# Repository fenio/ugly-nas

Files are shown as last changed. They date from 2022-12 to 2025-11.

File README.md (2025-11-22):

name

## DIY 8-disks NAS based on Odroid H3+ under $800 with disks

### Why is it ugly?

Well to be honest it's not so ugly anymore. 

But early case versions were really [ugly](/ugly) and when I eventually created decently looking case I decided to leave its name.

### So how does it look now?

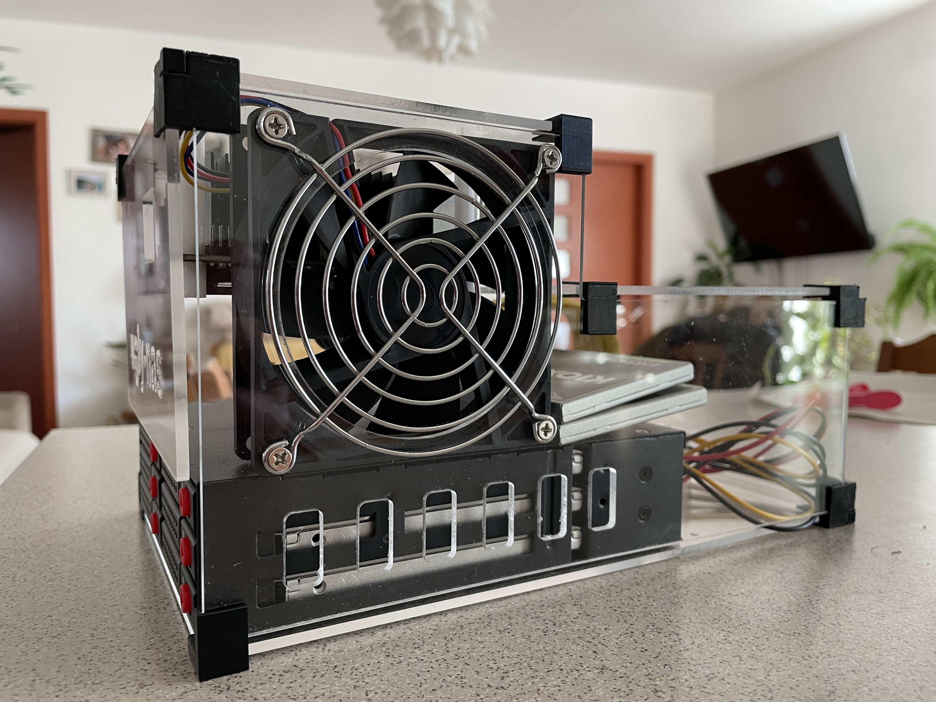
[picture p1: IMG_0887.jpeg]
nas1

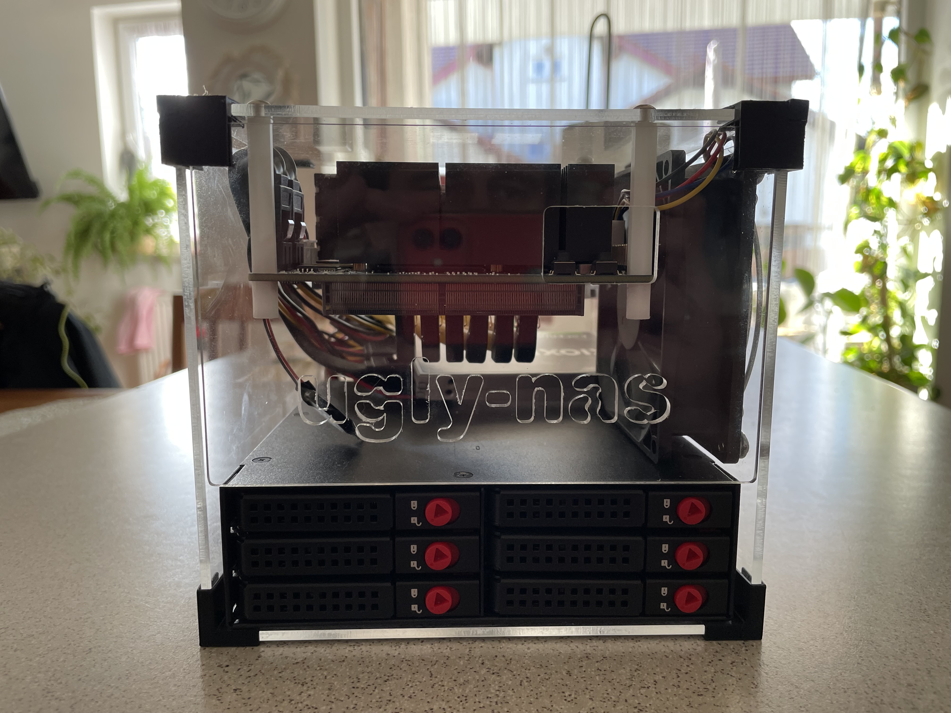
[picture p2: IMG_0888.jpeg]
nas2

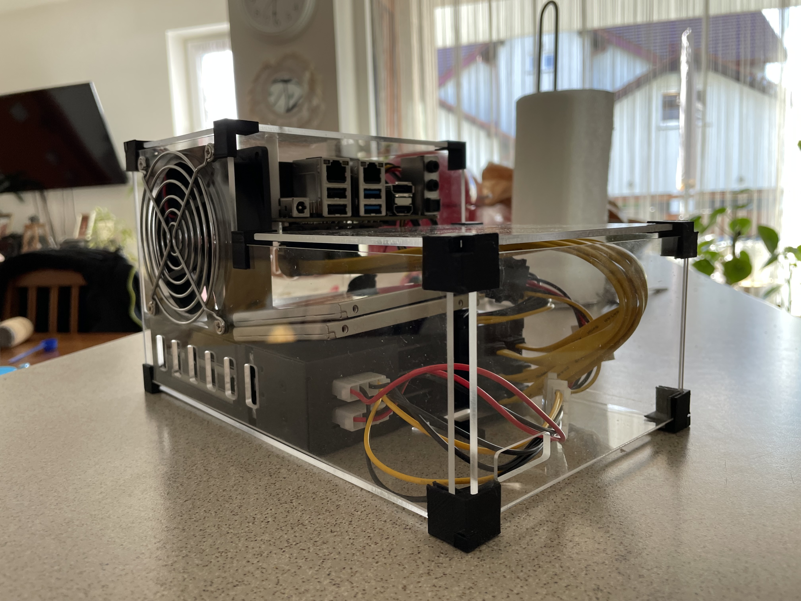
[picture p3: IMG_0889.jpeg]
nas3

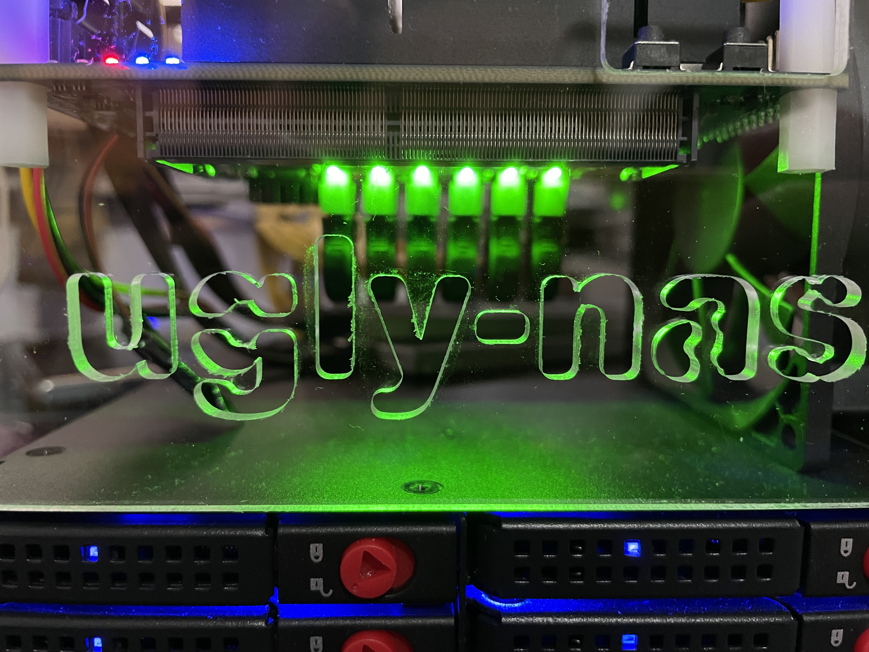
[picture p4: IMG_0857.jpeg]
nas4


Except it no longer has additional PSU for enclosure. Everything is powered using Odroid PSU.

### Cost (June 2023):

| Part  | USD  |
|---|---:|
| [Odroid H3+](https://www.hardkernel.com/shop/odroid-h3-plus/) | 165.00 |
| [64GB eMMC Module](https://www.hardkernel.com/shop/64gb-emmc-module-h2/) | 29.00 |
| [Samsung 32GB DDR4](https://www.hardkernel.com/shop/samsung-32gb-ddr4-pc4-25600-so-dimm/) | 99.00 |
| [Power Supply Unit](https://www.hardkernel.com/shop/15v-4a-power-supply-asia-korea-plug-copy/) | 9.40 |
| 2 x [SATA/Power cables for disks](https://www.hardkernel.com/shop/sata-data-and-power-cable/) | 6.00 |
| [Case Type 5](https://www.hardkernel.com/shop/odroid-h3-case-type-5/) | 20.00 |
| Shipping from hardkernel.com to Poland | 39.43 |
| 8 x [Kioxia 2.5" SSD 480GB drives](https://www.ebay.com/itm/134327464843) | ~330.00 |
| [6-bays enclosure](https://aliexpress.com/item/32921898033.html) | 48.29 |
| [PCI-E SATA extender for 6 ports](https://aliexpress.com/item/1005004374186238.html) | 24.80 |
| 6 x [Profiled SATA cables](https://pl.aliexpress.com/item/1005002384391035.html) | 16.74 |
| [MOLEX splitter](https://aliexpress.com/item/1005004236892928.html) | 1.71 |
| [SATA splitter](https://pl.aliexpress.com/item/10000330531380.html) | 1.57 |
| [Power extension](https://pl.aliexpress.com/item/1005001338498358.html) | 0.84 |
| **Sum** | **791.78** | 

Beware that I spent much more on experimenting with different setups. The final cost above is after refining the best solution.

If you opt for a self-designed [case](/case), purchasing a fan and supports separately is necessary.
From the [listing](https://www.hardkernel.com/shop/odroid-h3-case-type-5/) you will need these parts:

* G. 1 x 92x92x25mm DC 5V Cooling Fan
* H. 1 x 92mm Stainless Cooling Fan Grill
* I. 2 x 10mm (M/F) PCB Supports
* J. 1 x 40mm (M/F) PCB Supports
* K. 2 x 40mm (F/F) PCB Supports
* L. 4 x M5 PC Fan Screws
* N. 4 x 6mm M3 Truss Head Bolts

Assembling these parts individually may save some money, but purchasing the case directly from Odroid is more convenient for acquiring all necessary components in one go.

### Performance

    root@nas[/mnt/storage]# /root/fio --randrepeat=1 --ioengine=libaio --direct=1 --gtod_reduce=1 --name=test --filename=test.fio --bs=4k --iodepth=64 --size=1G --readwrite=randrw --rwmixread=80
    test: (g=0): rw=randrw, bs=(R) 4096B-4096B, (W) 4096B-4096B, (T) 4096B-4096B, ioengine=libaio, iodepth=64
    fio-3.25
    Starting 1 process
    test: Laying out IO file (1 file / 1024MiB)
    Jobs: 1 (f=1): [m(1)][100.0%][r=134MiB/s,w=33.0MiB/s][r=34.3k,w=8701 IOPS][eta 00m:00s]
    test: (groupid=0, jobs=1): err= 0: pid=691249: Mon Dec  5 18:10:27 2022
      read: IOPS=22.9k, BW=89.6MiB/s (93.9MB/s)(819MiB/9142msec)
       bw (  KiB/s): min=21781, max=165208, per=99.06%, avg=90861.61, stdev=42994.49, samples=18
       iops        : min= 5445, max=41302, avg=22715.33, stdev=10748.69, samples=18
      write: IOPS=5744, BW=22.4MiB/s (23.5MB/s)(205MiB/9142msec); 0 zone resets
       bw (  KiB/s): min= 5343, max=41728, per=99.04%, avg=22756.61, stdev=10894.22, samples=18
       iops        : min= 1335, max=10432, avg=5689.06, stdev=2723.60, samples=18
      cpu          : usr=5.09%, sys=78.22%, ctx=5155, majf=4, minf=7
      IO depths    : 1=0.1%, 2=0.1%, 4=0.1%, 8=0.1%, 16=0.1%, 32=0.1%, >=64=100.0%
         submit    : 0=0.0%, 4=100.0%, 8=0.0%, 16=0.0%, 32=0.0%, 64=0.0%, >=64=0.0%
         complete  : 0=0.0%, 4=100.0%, 8=0.0%, 16=0.0%, 32=0.0%, 64=0.1%, >=64=0.0%
         issued rwts: total=209630,52514,0,0 short=0,0,0,0 dropped=0,0,0,0
         latency   : target=0, window=0, percentile=100.00%, depth=64

    Run status group 0 (all jobs):
       READ: bw=89.6MiB/s (93.9MB/s), 89.6MiB/s-89.6MiB/s (93.9MB/s-93.9MB/s), io=819MiB (859MB), run=9142-9142msec
      WRITE: bw=22.4MiB/s (23.5MB/s), 22.4MiB/s-22.4MiB/s (23.5MB/s-23.5MB/s), io=205MiB (215MB), run=9142-9142msec

And same test with 10M file instead of 1G:

    root@nas[/mnt/storage]# /root/fio --randrepeat=1 --ioengine=libaio --direct=1 --gtod_reduce=1 --name=test --filename=test.fio --bs=4k --iodepth=64 --size=10M --readwrite=randrw --rwmixread=80
    test: (g=0): rw=randrw, bs=(R) 4096B-4096B, (W) 4096B-4096B, (T) 4096B-4096B, ioengine=libaio, iodepth=64
    fio-3.25
    Starting 1 process

    test: (groupid=0, jobs=1): err= 0: pid=695373: Mon Dec  5 18:25:17 2022
      read: IOPS=97.1k, BW=379MiB/s (398MB/s)(8156KiB/21msec)
      write: IOPS=24.8k, BW=96.9MiB/s (102MB/s)(2084KiB/21msec); 0 zone resets
      cpu          : usr=0.00%, sys=90.00%, ctx=0, majf=0, minf=7
      IO depths    : 1=0.1%, 2=0.1%, 4=0.2%, 8=0.3%, 16=0.6%, 32=1.2%, >=64=97.5%
         submit    : 0=0.0%, 4=100.0%, 8=0.0%, 16=0.0%, 32=0.0%, 64=0.0%, >=64=0.0%
         complete  : 0=0.0%, 4=100.0%, 8=0.0%, 16=0.0%, 32=0.0%, 64=0.1%, >=64=0.0%
         issued rwts: total=2039,521,0,0 short=0,0,0,0 dropped=0,0,0,0
         latency   : target=0, window=0, percentile=100.00%, depth=64

    Run status group 0 (all jobs):
       READ: bw=379MiB/s (398MB/s), 379MiB/s-379MiB/s (398MB/s-398MB/s), io=8156KiB (8352kB), run=21-21msec
      WRITE: bw=96.9MiB/s (102MB/s), 96.9MiB/s-96.9MiB/s (102MB/s-102MB/s), io=2084KiB (2134kB), run=21-21msec

With iozone:

    root@nas[/mnt/storage]# /root/iozone -e -I -a -s 1G -r 4k -r 16k -r 512k -r 1024k -r 16384k -i 0 -i 1 -i 2     
            Iozone: Performance Test of File I/O
                    Version $Revision: 3.489 $
                    Compiled for 64 bit mode.
                    Build: linux-AMD64 
    
            Contributors:William Norcott, Don Capps, Isom Crawford, Kirby Collins
                         Al Slater, Scott Rhine, Mike Wisner, Ken Goss
                         Steve Landherr, Brad Smith, Mark Kelly, Dr. Alain CYR,
                         Randy Dunlap, Mark Montague, Dan Million, Gavin Brebner,
                         Jean-Marc Zucconi, Jeff Blomberg, Benny Halevy, Dave Boone,
                         Erik Habbinga, Kris Strecker, Walter Wong, Joshua Root,
                         Fabrice Bacchella, Zhenghua Xue, Qin Li, Darren Sawyer,
                         Vangel Bojaxhi, Ben England, Vikentsi Lapa,
                         Alexey Skidanov, Sudhir Kumar.
    
            Run began: Mon Jan 16 16:52:27 2023
    
            Include fsync in write timing
            O_DIRECT feature enabled
            Auto Mode
            File size set to 1048576 kB
            Record Size 4 kB
            Record Size 16 kB
            Record Size 512 kB
            Record Size 1024 kB
            Record Size 16384 kB
            Command line used: /root/iozone -e -I -a -s 1G -r 4k -r 16k -r 512k -r 1024k -r 16384k -i 0 -i 1 -i 2
            Output is in kBytes/sec
            Time Resolution = 0.000001 seconds.
            Processor cache size set to 1024 kBytes.
            Processor cache line size set to 32 bytes.
            File stride size set to 17 * record size.
                                                                  random    random     bkwd    record    stride                                    
                  kB  reclen    write  rewrite    read    reread    read     write     read   rewrite      read   fwrite frewrite    fread  freread
             1048576       4   310964   292306  1178512  1179537   173968   195313                                                                
             1048576      16   293274   307902  2134753  2159181   626843   278066                                                                
             1048576     512  1010432  1793142  6357664  2866019  3240346   999201                                                                
             1048576    1024   798928  1539648  4325665  4094047  6342773  1731892                                                                
             1048576   16384   809463  1588195  4512099  2468875  2813374  1110396                                                                
    
    iozone test complete.

And simple dd:

    root@nas[~]# dd if=/dev/zero of=/mnt/storage/file bs=1M count=10K
    10240+0 records in
    10240+0 records out
    10737418240 bytes (11 GB, 10 GiB) copied, 6.14285 s, 1.7 GB/s
    root@nas[~]# dd if=/mnt/storage/file of=/dev/null bs=1M count=10K
    10240+0 records in
    10240+0 records out
    10737418240 bytes (11 GB, 10 GiB) copied, 2.27149 s, 4.7 GB/s

Feel free to ping me if you want me to run any other tests.

### Power consumption in Watts

| State | Peak | Avg |
|---|---:|---:|
| standby | - | 3.6 |
| boot | 24.2 | ~17 |
| idling | 17.7 | ~14 |
| 1 VM running | 22.3 | ~16 |
| VM + stress CPU + fio test | 30.8 | ~28 |

Note: Don't try to use HDD instead of SDD with my power supply setup... it won't work almost for sure.

### Does it support ECC?

No. It can't.

### What software does it run?

It runs TrueNAS Scale.
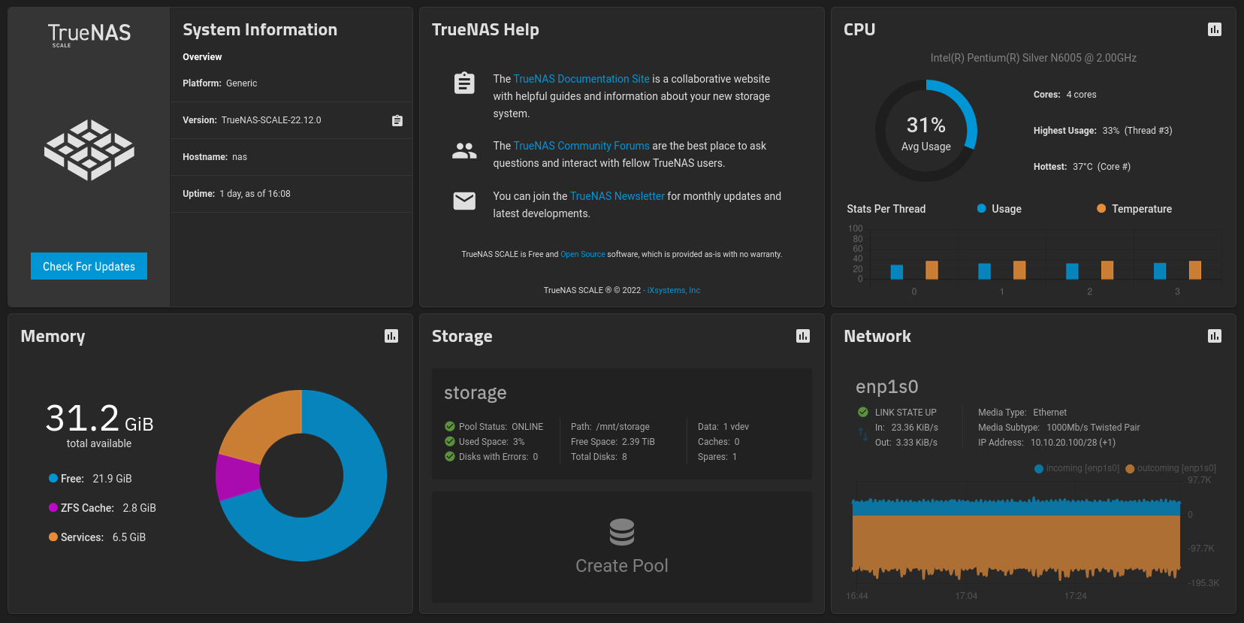
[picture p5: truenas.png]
truenas


Side note. Make sure to use the latest intel microcode or you'll end up with VM's freezing here and there pretty often.
You have to have microcode version "24" to have stable virtualization.

    root@nas[~]# grep -m1 microcode /proc/cpuinfo 
    microcode       : 0x24000024

If it shows 0x24000023 then you definitely want to update it.

### Can it be any cheaper?

Yup.

Without disks it's below $500 ;)

Also it should still work pretty decent if you switch:
  * H3+ -> H3 - 36$ less
  * eMMC 64GB -> 32GB - $10 less
  * RAM 32GB -> 16GB - $54 less

So without disks it can be built for about $375.

### Why are two disks directly plugged into Odroid not part of enclosure?

Odroid [doesn't](https://wiki.odroid.com/odroid-h3/hardware) support hotplug for devices directly attached to it so it doesn't really make sense to make them part of enclosure.

### How to get that lovely case?

All needed parts are listed [there](/case).

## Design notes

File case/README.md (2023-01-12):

# Parts needed to create the case

## Plexiglass to be carved by local CNC supplier (3mm)

* [Front](front.svg)
* [Back](back.svg)
* [Left](left.svg)
* [Right](right.svg)
* [Shelve](shelve.svg)
* [Top](top.svg)
* [Bottom](bottom.svg)

## Connectors to be printed in 3D

| Part | Pcs | Link | File |
|---|----:|---|---|
| 3-way connector | 6 | https://www.tinkercad.com/things/dNCOjgzWop4-corner-connector-3-way | [Corner connector 3-way](Corner-3W.stl) |
| 2-way open | 4 | https://www.tinkercad.com/things/0fqsxl175nB-corner-connector-2-way-half-open | [Corner connector 2-way open](Corner-2W-open.stl) |
| 2-way | 4 | https://www.tinkercad.com/things/dEiUtZarAht-corner-connector-2-way | [Corner connector 2-way](Corner-2W.stl) |
| Peg | 6 | https://www.tinkercad.com/things/g6Oe3tnbkLx-peg | [Peg](Peg.stl) |
| Blocker | 1 | https://www.tinkercad.com/things/gxXk9fNjbbF-blocker | [Blocker](Blocker.stl) |

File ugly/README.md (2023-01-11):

Case evolution

# Why was it ugly?

# Odroid case
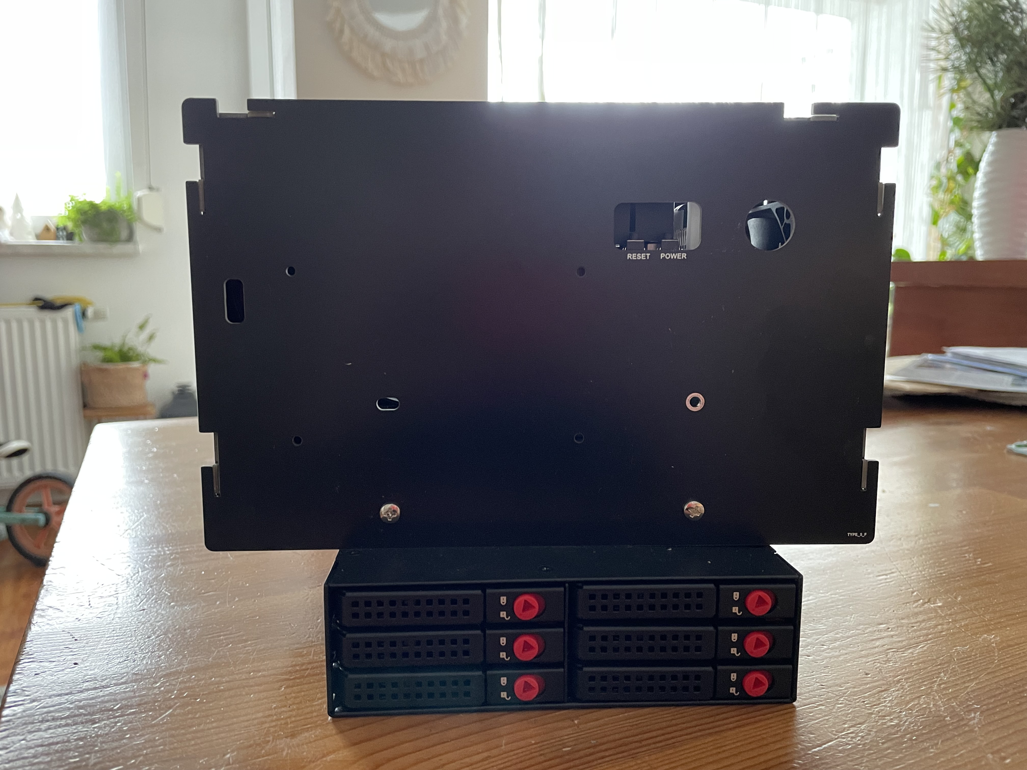
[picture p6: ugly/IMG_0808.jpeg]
early1

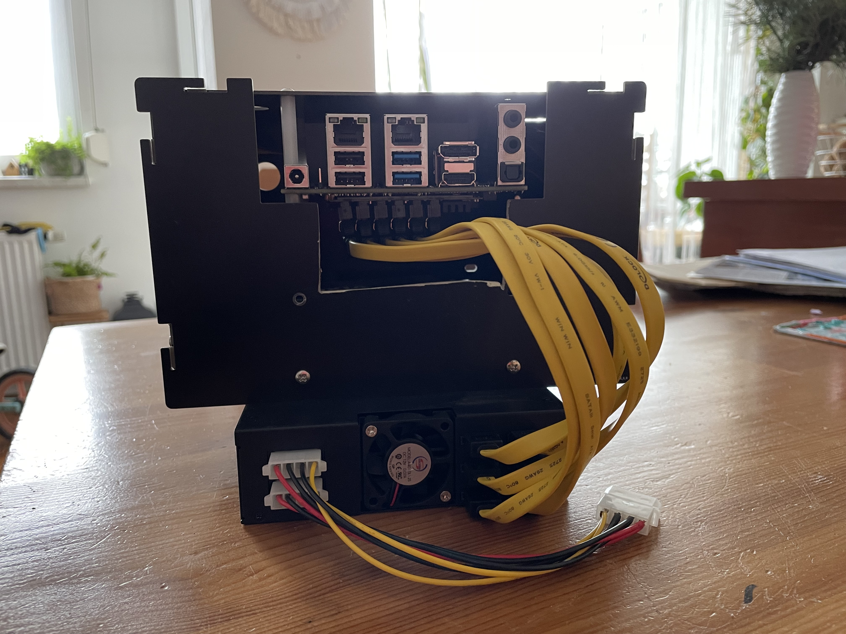
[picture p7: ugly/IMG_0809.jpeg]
early2

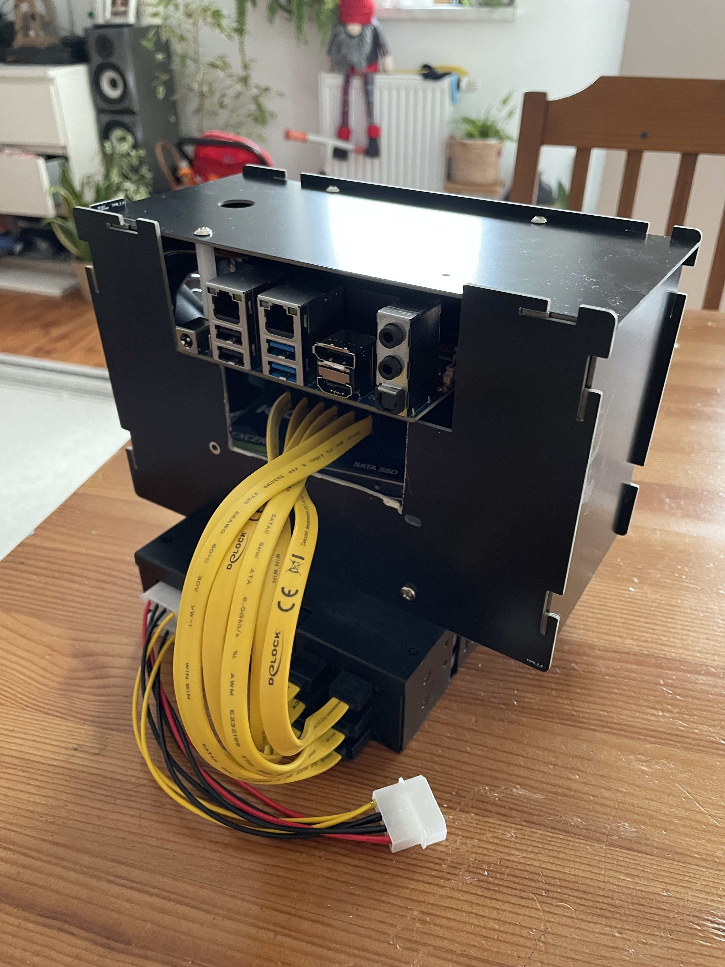
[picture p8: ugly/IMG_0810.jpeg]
early3


# Early attempt
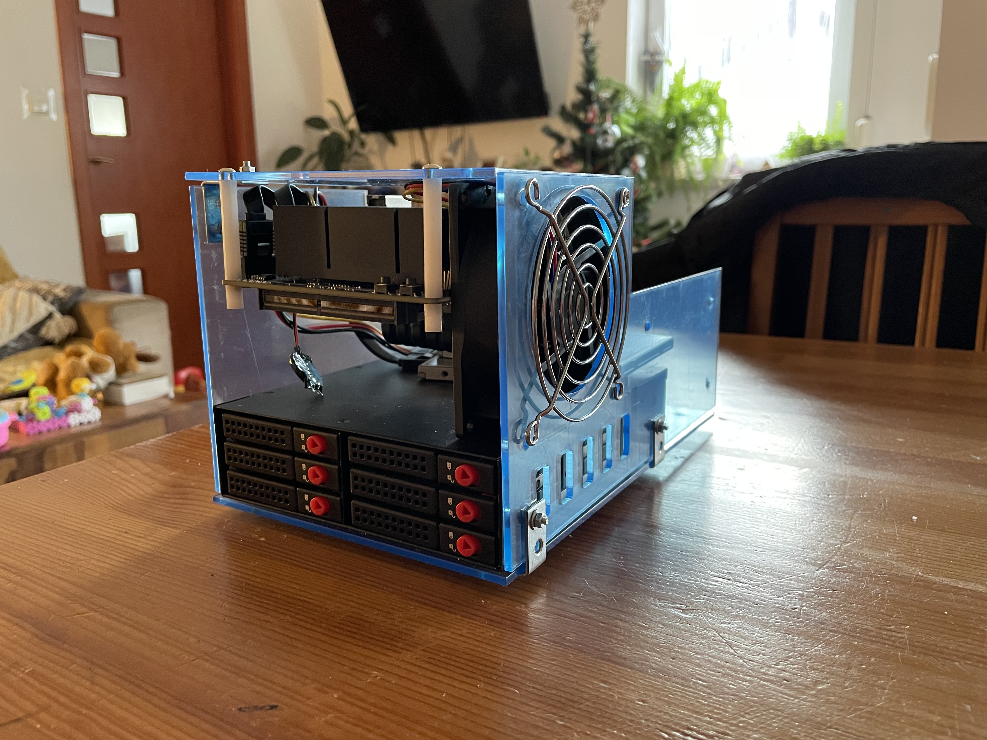
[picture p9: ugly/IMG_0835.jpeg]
alpha1

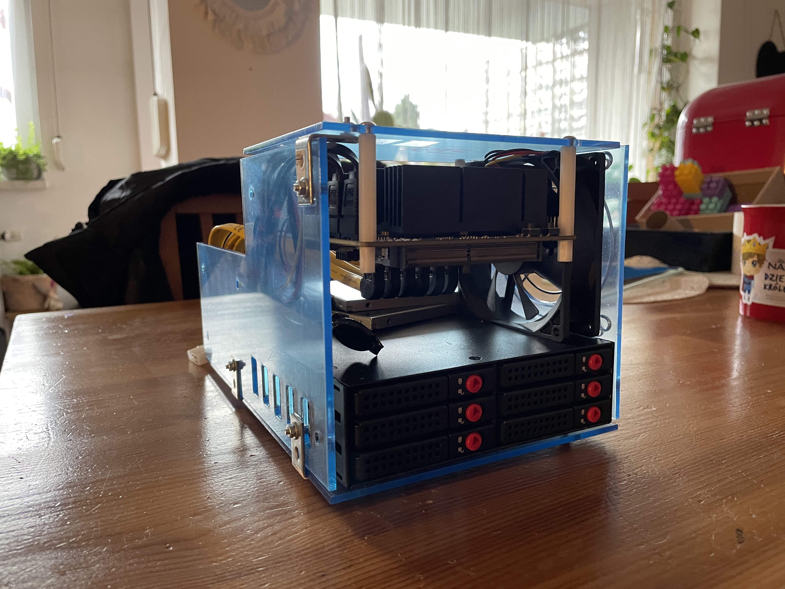
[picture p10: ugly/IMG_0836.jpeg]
alpha2

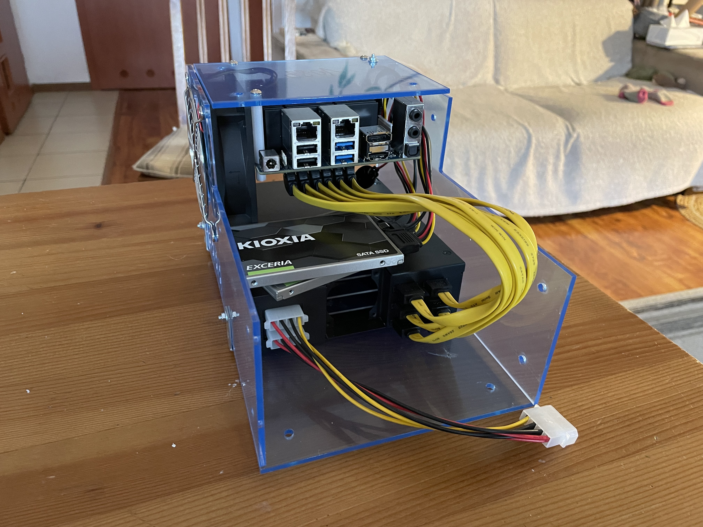
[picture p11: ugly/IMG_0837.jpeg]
alpha3


# Another approach
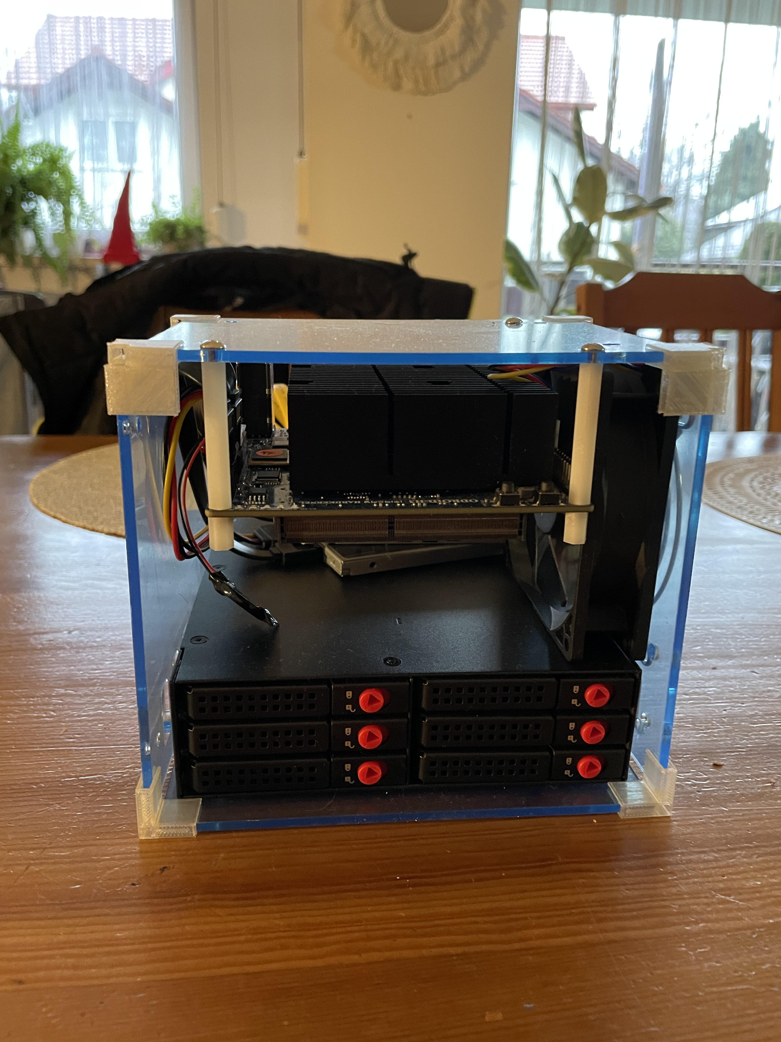
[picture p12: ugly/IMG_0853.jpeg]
beta1


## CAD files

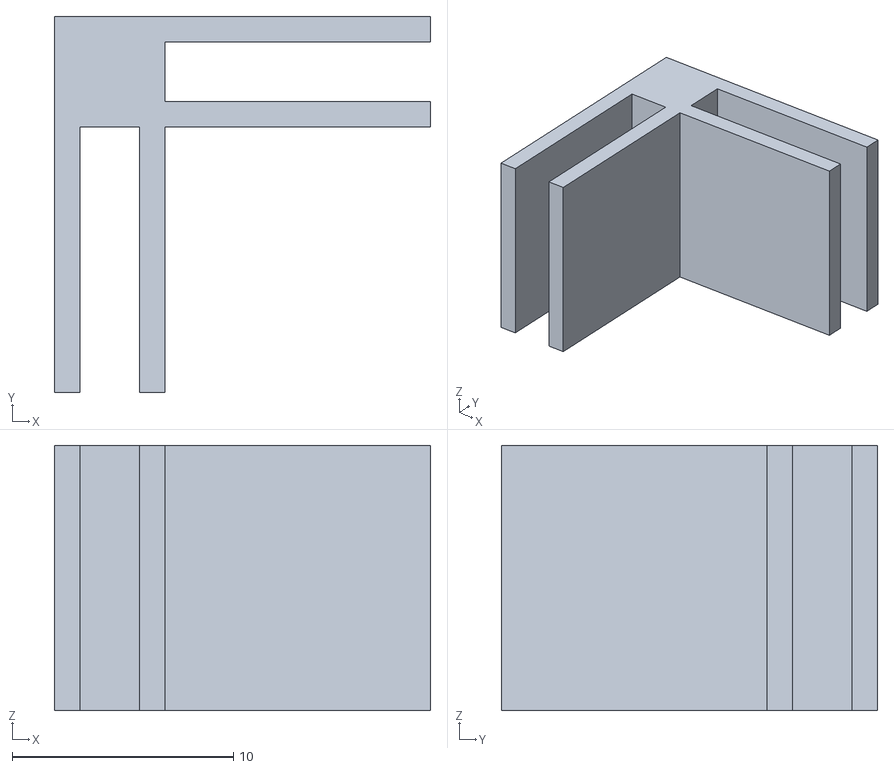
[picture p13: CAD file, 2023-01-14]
case/Corner-2W-open.stl
17.0 x 17.0 x 12.0

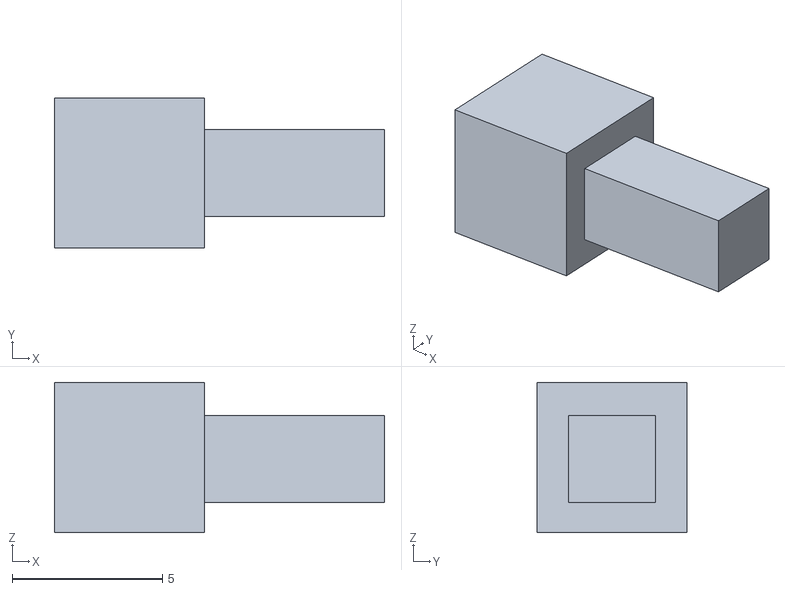
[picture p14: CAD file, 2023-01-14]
case/Peg.stl
11.0 x 5.00 x 5.00

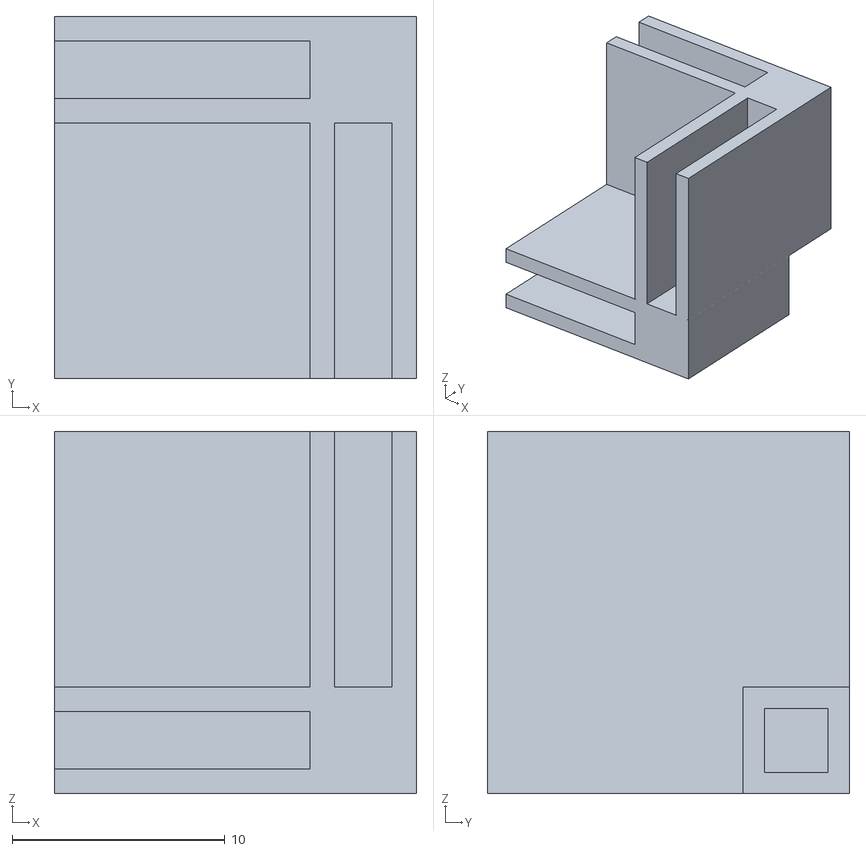
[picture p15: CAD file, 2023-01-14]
case/Corner-3W.stl
17.0 x 17.0 x 17.0

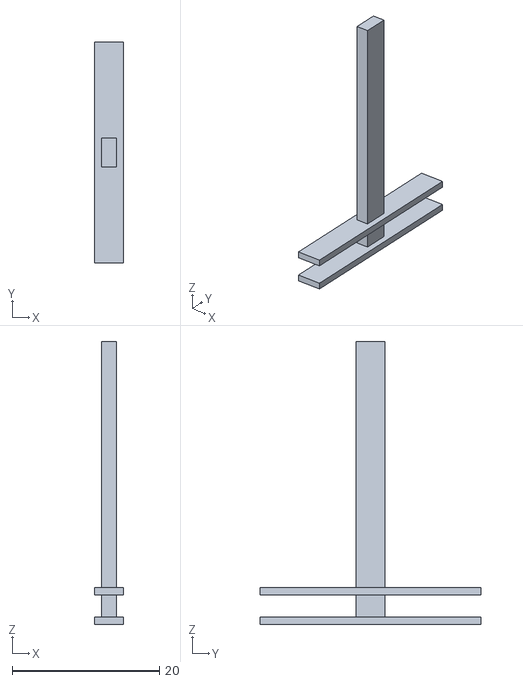
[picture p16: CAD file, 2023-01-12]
case/Blocker.stl
4.00 x 30.0 x 38.5

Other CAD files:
case/Corner-2W.stl

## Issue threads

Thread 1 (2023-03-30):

Need help with providing power to disk enclosure in UGLY NAS

lambscaped, 2023-03-30:
I've been working on building my own NAS using your project as a guide and I really like it! However, I'm having trouble figuring out how to provide power to the disk enclosure through the odroid H3+. I was hoping you could help me by letting me know what physical components you used and how you made it work.

Thank you for your contribution to the community, and I look forward to hearing back from you!

Best regards,
Sergio Leyva

fenio, 2023-03-31:
Hey @lambscaped

Thanks for your report and yeah I should probably spend some time to update description to include final list of components.
Basically you just need two relatively cheap splitters in addition to what's listed.

I bought them on Allegro (let's call it Polish equivalent of Ebay).
[https://allegro.pl/oferta/kabel-zasilajacy-sata-podwojny-15cm-gembird-10973469194](SATA)
[https://allegro.pl/oferta/przejsciowka-kabel-sata-na-molex-15cm-lanberg-12481969887](Molex)

I found them also on Amazon but they are like 4x more expensive there:
[https://amzn.eu/d/5TaBAqU](SATA)
[https://amzn.eu/d/3ip2pUE](MOLEX)

Hope that helps.

lambscaped, 2023-03-31:
Thanks a lot for the quick response and again for sharing with the
community i already bought the cable splitters threw aliexpress;

Have a nice spring day in Poland

El vie, 31 mar 2023 a las 6:56, Bartosz Fenski ***@***.***>)
escribió:

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

fenio, 2023-04-05:
Can you share a links to Aliexpress?
I will update the list ;)

lambscaped, 2023-04-05:
Sure, here it is.
 € 1,45 | SATA II Hard Disk Power 15Pin SATA Male To 2 Female 15Pin Power
HDD Splitter High Quality Y 1 To 2 Extension Cable 20CM
https://a.aliexpress.com/_msgWjGs

€ 0,78 | SATA Power Extension Cable Serial ATA 15pin Male To Molex IDE 4pin
Female Power Supply For HDD Hard Disk Hard Drive
https://a.aliexpress.com/_msdB8kM

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

fenio, 2023-04-07:
Thanks a lot. I've updated list of needed components thus I'm closing this issue ;)

nettnikl, 2023-09-02:
Hey, i bought these, and it seems you need a SATA splitter + SATA Male To __2x__ Molex - the one linked here only has one Molex - does the cooler of the bay work with only one Molex connected to power? What are you supposed to connect? On the images sadly the cables are mostly hidden, and only the only one showing the cables (IMG_0889.jpeg) - has the black edge exactly in front of the relevant parts.

fenio, 2023-09-23:
@nettnikl whole bay is powered in kinda weird way. One molex powers 4 disks and the other one remaining 2 of them.
Not sure which one powers fan as well since I removed it as it was too loud and I think in case of SSDs it's not so important. My setup (the one I use in real) in not really optimal since initially my plan was to power bay externally. Then I realized that there's enough power in Odroid itself so I took power from it but at the same time I wanted to reuse wires I already had. But if I recall correctly despite me having not optimal wiring I updated list that someone else could have optimal one. I'm not sure though since it was few months ago.

nettnikl, 2023-09-23:
@fenio Your answer is much appreciated, thanks! Okay, so i understand your reasoning. Looking at my situation though, i'm still a bit unsure.. Maybe, sorry if asking too much, could you take a photo of your cables? Even if, as mentioned, sub- optimal, i'd be helpful to see a working setup.

fenio, 2023-09-24:
@nettnikl I was in a good mood today and specially for you grabbed it from my lab shelf ;)

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

fenio, 2023-09-24:
@nettnikl
But in order to make it optimal at least from power usage perspective so 4 disks on one power output and 4 disks on another one you would have to do it this way:

* 1st output from Odroid

Mini 4-pin (2.54mm pitch) to SATA 15-pin
https://www.hardkernel.com/shop/sata-data-and-power-cable/

Then split it with SATA splitter:
https://pl.aliexpress.com/item/10000330531380.html

So now you've got two SATA

One SATA 15-pin to MOLEX - to power 2 disks from enclosure
https://pl.aliexpress.com/item/1005001338498358.html

And the other SATA needs to be split again with
https://pl.aliexpress.com/item/10000330531380.html
to power two disks which are outside of enclosure.

* 2nd output from Odroid

We're starting again with
Mini 4-pin (2.54mm pitch) to SATA 15-pin
https://www.hardkernel.com/shop/sata-data-and-power-cable/
to have regular SATA

Then just conversion to MOLEX with:
https://pl.aliexpress.com/item/1005001338498358.html

Obviously if you find wire which converts Mini 4-pin straight to the MOLEX then you can skip SATA part.

Hope that helps.

nettnikl, 2023-09-24:
Thank you so much! Yeah, you bet it helps!

nettnikl, 2023-11-16:
PSA:
It seems in my case, the upper molex powers the fan and the upper 4 disks, the lower molex the lower 2 disks.
I'm now trying to distribute the power otherwise, with
- mini sata power output 1
  -> to sata power
  -> to to molex
  - to upper case input
    -> to case fan
    -> to disk 1
    -> to disk 2
    -> to disk 3
    -> to disk 4
- mini sata power output 2
  -> to sata power
  -> to splitter
  - to lower case input
    -> to disk 5
    -> to disk 6
  - to second splitter
    -> to disk 7 (not in 6x case)
    -> to disk 8 (not in 6x case)

fenio, 2023-11-17:
If I'm reading it correctly then it's more or less the same setup I described just with different order. In my case 2nd output for used to power 4 disks in enclosure and you did it with 1st output.
Anyway I'm glad that you made it working ;)

Closed 2023-04-07.

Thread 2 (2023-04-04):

2x 4-bay enclosure

larseggert, 2023-04-04:
Thanks for the build writeup! Sorry, some hopefully easy questions:

I'm wondering if there are any upsides/downsides to using two [4-bay enclosures](https://www.aliexpress.com/item/1005004857864989.html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) for the eight disks, rather than your current build?

Also, for the [Case Type 5](https://www.hardkernel.com/shop/odroid-h3-case-type-5/), it says "Net card is necessary to assemble this case", but your build does not seem to include that? Would a [Case Type 3](https://www.hardkernel.com/shop/odroid-h3-case-type-3/) work to contain two SSDs, and then the other six would go into the 6-bay enclosure from your build list?

fenio, 2023-04-04:
Hey @larseggert

So the reason I haven''t decided to use 8 bays or 2x4 bays enclosure(s) is because Odroid doesn't support hotplug for the drives directly attached to it. So while technically you can of course ignore that fact and put all the drives into enclosures then you'll be at risk of damaging Odroid by removing one of these two disks during work. I wanted to avoid that risk.

I mentioned it also in the [writeup](https://github.com/fenio/ugly-nas#why-are-two-disks-directly-plugged-into-odroid-not-part-of-enclosure)

Speaking about cases - type 5 vs type 3 - to be honest I left case on the listing mostly because in the end I used some parts (supports, fan) from it but as you can see on the pictures my case is DIY solution and you you buy supports, fan separately then you don't really need case from Odroid. I chose type 5 case at the beginning cause initial vision was slightly different from what I did at the end. After all whole solution was evolving and I tried several approaches.

fenio, 2023-04-05:
I guess the reason they do just 6-bays is because of its dimensions. It's meant to be put in 5,25" aka CDROM/DVD bay in PC. Not sure if they do also 8-bay versions.

Speaking about power adaptor. Again it my case the setup is made this way since initially I wasn't even sure if I can use just PSU attached to Odroid. Initially I wanted to power enclosure separately. But then I made some measurements and it turned out that power from Odroid itself should be enough. I'm also not using any additional stuff connected to USB and so on and *just* SSD disks. If you're planning to use more peripherials or different disks then maybe it makes sense to get more powerful adaptor.

larseggert, 2023-04-05:
Thanks!

I ordered the largest case and no drive enclosure - will just keep the drives in there...

Will update you how my build goes once parts arrive.

fenio, 2023-07-22:
How did it go? ;)

larseggert, 2023-07-22:
Has been working great!

fenio, 2023-07-22:
Glad to hear that! Congratulations ;)
Does it mean that the issue has been solved and I can close it? :)

larseggert, 2023-07-22:
Oh, yes!

Closed 2023-07-22.

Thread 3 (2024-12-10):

wrong link for the power extensions

iggi42, 2024-12-10:
you got the wrong link in the README for the the power extensions, I think?
It is the same as the SATA splitter :')

https://pl.aliexpress.com/item/1005001338498358.html

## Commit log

2022-12-30 new case
2022-12-30 case updates
2023-01-10 power usage update
2023-01-10 case update
2023-01-11 another case
2023-01-11 current look
2023-01-11 case files
2023-01-12 STL files
    [Blocker.stl, Corner connector 2-way half-open.stl, Corner connector 2-way.stl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]
2023-01-12 fix paths
    [Corner-2W-ho.stl, Corner-2W.stl, Corner-3W.stl]
2023-01-12 change name
    [Corner-2W-open.stl]
2025-11-22 fix link to power extension
